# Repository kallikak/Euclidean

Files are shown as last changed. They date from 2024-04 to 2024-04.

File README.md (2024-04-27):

# Euclidean

This is the repository for the code for The EUCLIDEAN synthesiser. The main sketch is in the Euclid folder, but to build it some small changes need to be made to the Teensyduino environment.

- In order to use the Ensemble effect, the two files effect_ensemble.c and effect_ensemble.h need to be added to the audio library, and effect_ensemble.h added to the Audio.h header.

- The ST7735_t3 library is used for the LCD. The fonts I use are in the Fonts folder, and need to be added to the library if not already present.

- The other libraries needed are:
  - IntervalTimer
  - Bounce2mcp
  - Adafruit_MCP23017
  - MIDI
  - USBHost_t36
  - SD_t3.h
  - ADC (only needed if for some reason the pots are particularly noisy/jittery)

- You cannot use the default Audio Library GUI with the code from Euclid.ino because it doesn't recognise AudioEffectEnsemble.  The easiest change is to make it AudioEffectChorus  instead (and change AudioConnection patchCord60(chorus, 1, effectmixR, 1) to AudioConnection patchCord60(chorus, 0, effectmixR, 1)), but remember to change it back if you make changes and want to update.

- Compile with USB type set to Serial + MIDI + Audio, and no harm overclocking to 816MHz.

- Prebuilt hex files are provided for both Teensy 4.0 and Teensy 4.1.

A User Guide for the synthesizer is here: http://thewessens.net/Euclid/Docs/User/euclideaninfo.html

A Build Guide for the kit is here: http://thewessens.net/Euclid/Docs/Build/euclideanbuild.html

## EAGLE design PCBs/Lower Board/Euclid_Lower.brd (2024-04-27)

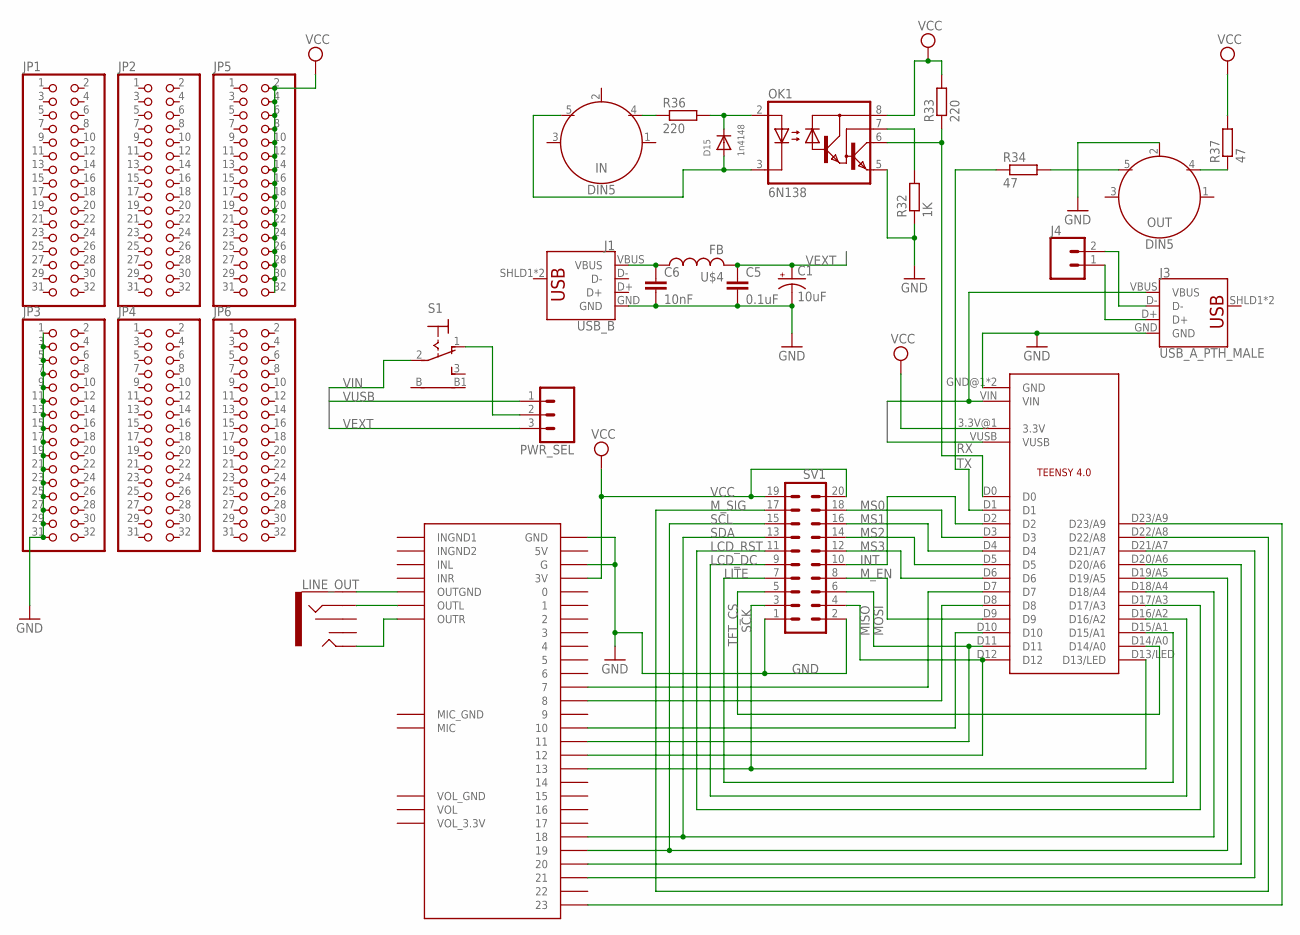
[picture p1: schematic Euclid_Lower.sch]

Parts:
C1: 10uF; TT5D6
C5: 0.1uF; C025-025X050
C6: 10nF; C025-025X050
D15: 1n4148; DO-1N4148
IN: DIN5; DIN5-RA-PTH
J1: USB_B; USB-B-NO-OVERHANG
J3: USB_A_PTH_MALE; USB-A-H
J4: CONN_02; 1X02
JP1, JP2, JP3, JP4, JP5, JP6: PINHD-2X16; 2X16
LINE_OUT: AUDIO_JACK_3.5MM_KIT; AUDIO-JACK-KIT
OK1: 6N138; DIL08
OUT: DIN5; DIN5-RA-PTH
PWR_SEL: 455-1750-1-ND; 1X03
R32: 1K; 0207/10
R33, R36: 220; 0207/10
R34, R37: 47; 0207/10
S1: 9070-1W
SV1: MA10-2
U$1: TEENSY4.0_SIMPLE
U$3: AUDIOSHIELD
U$4: FB

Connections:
D+: J3.D+, J4.1
D-: J3.D-, J4.2
GND: C1.-, C5.2, C6.2, J1.GND, J3.GND, JP3.1, JP3.3, JP3.5, JP3.7, JP3.9, JP3.11, JP3.13, JP3.15, JP3.17, JP3.19, JP3.21, JP3.23, JP3.25, JP3.27, JP3.29, JP3.31, OK1.5 (GND), OUT.2, R32.1, SV1.1, SV1.2, U$1.GND@1 (GND), U$1.GND@2 (GND), U$3.G, U$3.GND
INT: SV1.10, U$1.D2
LCD_DC: SV1.9, U$1.D16/A2
LCD_RST: SV1.11, U$1.D17/A3
LITE: SV1.7, U$1.D15/A1
MISO: SV1.4, U$1.D12, U$3.12
MOSI: SV1.6, U$1.D11, U$3.11
MS0: SV1.18, U$1.D3
MS1: SV1.16, U$1.D4
MS2: SV1.14, U$1.D5
MS3: SV1.12, U$1.D6
M_EN: SV1.8, U$1.D9
M_SIG: SV1.17, U$1.D22/A8
unnamed: U$1.D20/A6, U$3.20
unnamed: U$1.D21/A7, U$3.21
unnamed: U$1.D23/A9, U$3.23
unnamed: U$1.D10, U$3.10
unnamed: U$1.D7, U$3.7
unnamed: U$1.D8, U$3.8
unnamed: PWR_SEL.2, S1.1 (O)
unnamed: OUT.5, R34.2
unnamed: OK1.7 (VB), R32.2
unnamed: D15.A, IN.5, OK1.3 (C)
unnamed: D15.C, OK1.2 (A), R36.2
unnamed: IN.4, R36.1
unnamed: LINE_OUT.SLEEVE, U$3.OUTGND
unnamed: C6.1, J1.VBUS, U$4.P$1 (1)
unnamed: OUT.4, R37.1
unnamed: LINE_OUT.RING, U$3.OUTL
unnamed: LINE_OUT.TIP, U$3.OUTR
RX: OK1.6 (VO), R33.1, U$1.D0
SCK: SV1.3, U$1.D13/LED, U$3.13
SCL: SV1.15, U$1.D19/A5, U$3.19
SDA: SV1.13, U$1.D18/A4, U$3.18
TFT_CS: SV1.5, U$1.D14/A0
TX: R34.1, U$1.D1
VCC: JP5.2, JP5.4, JP5.6, JP5.8, JP5.10, JP5.12, JP5.14, JP5.16, JP5.18, JP5.20, JP5.22, JP5.24, JP5.26, JP5.28, JP5.30, JP5.32, OK1.8 (VCC), R33.2, R37.2, SV1.19, SV1.20, U$1.3.3V@1 (3.3V), U$3.3V
VEXT: C1.+, C5.1, PWR_SEL.3, U$4.P$2 (2)
VIN: J3.VBUS, S1.2, U$1.VIN
VUSB: PWR_SEL.1, U$1.VUSB

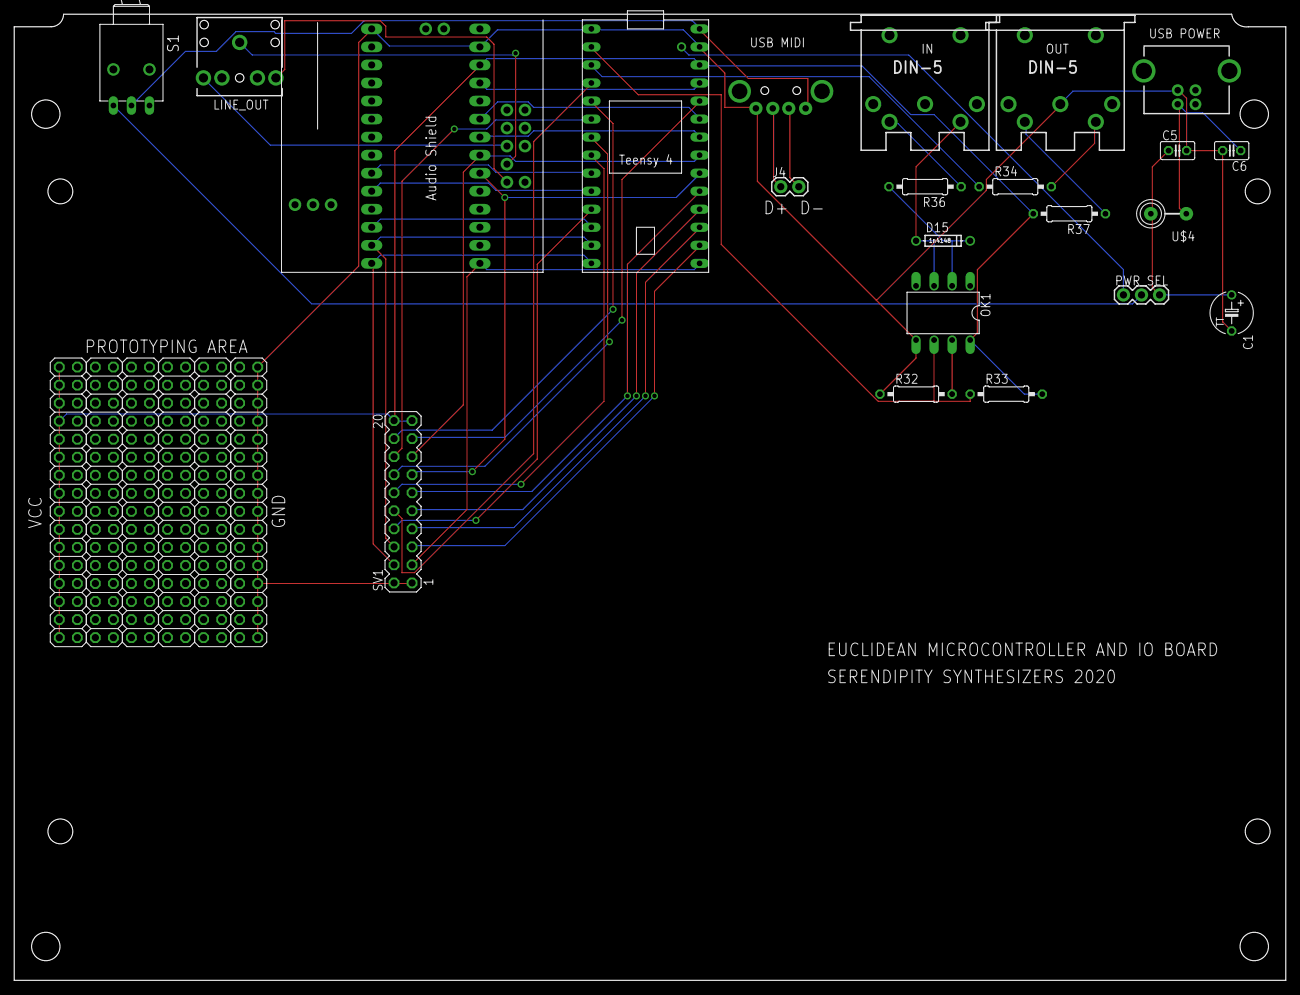
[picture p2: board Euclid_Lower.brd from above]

Board: 2 copper layers, 179.1 x 136.1 mm, 28 parts (1 on the bottom side), 42 nets.

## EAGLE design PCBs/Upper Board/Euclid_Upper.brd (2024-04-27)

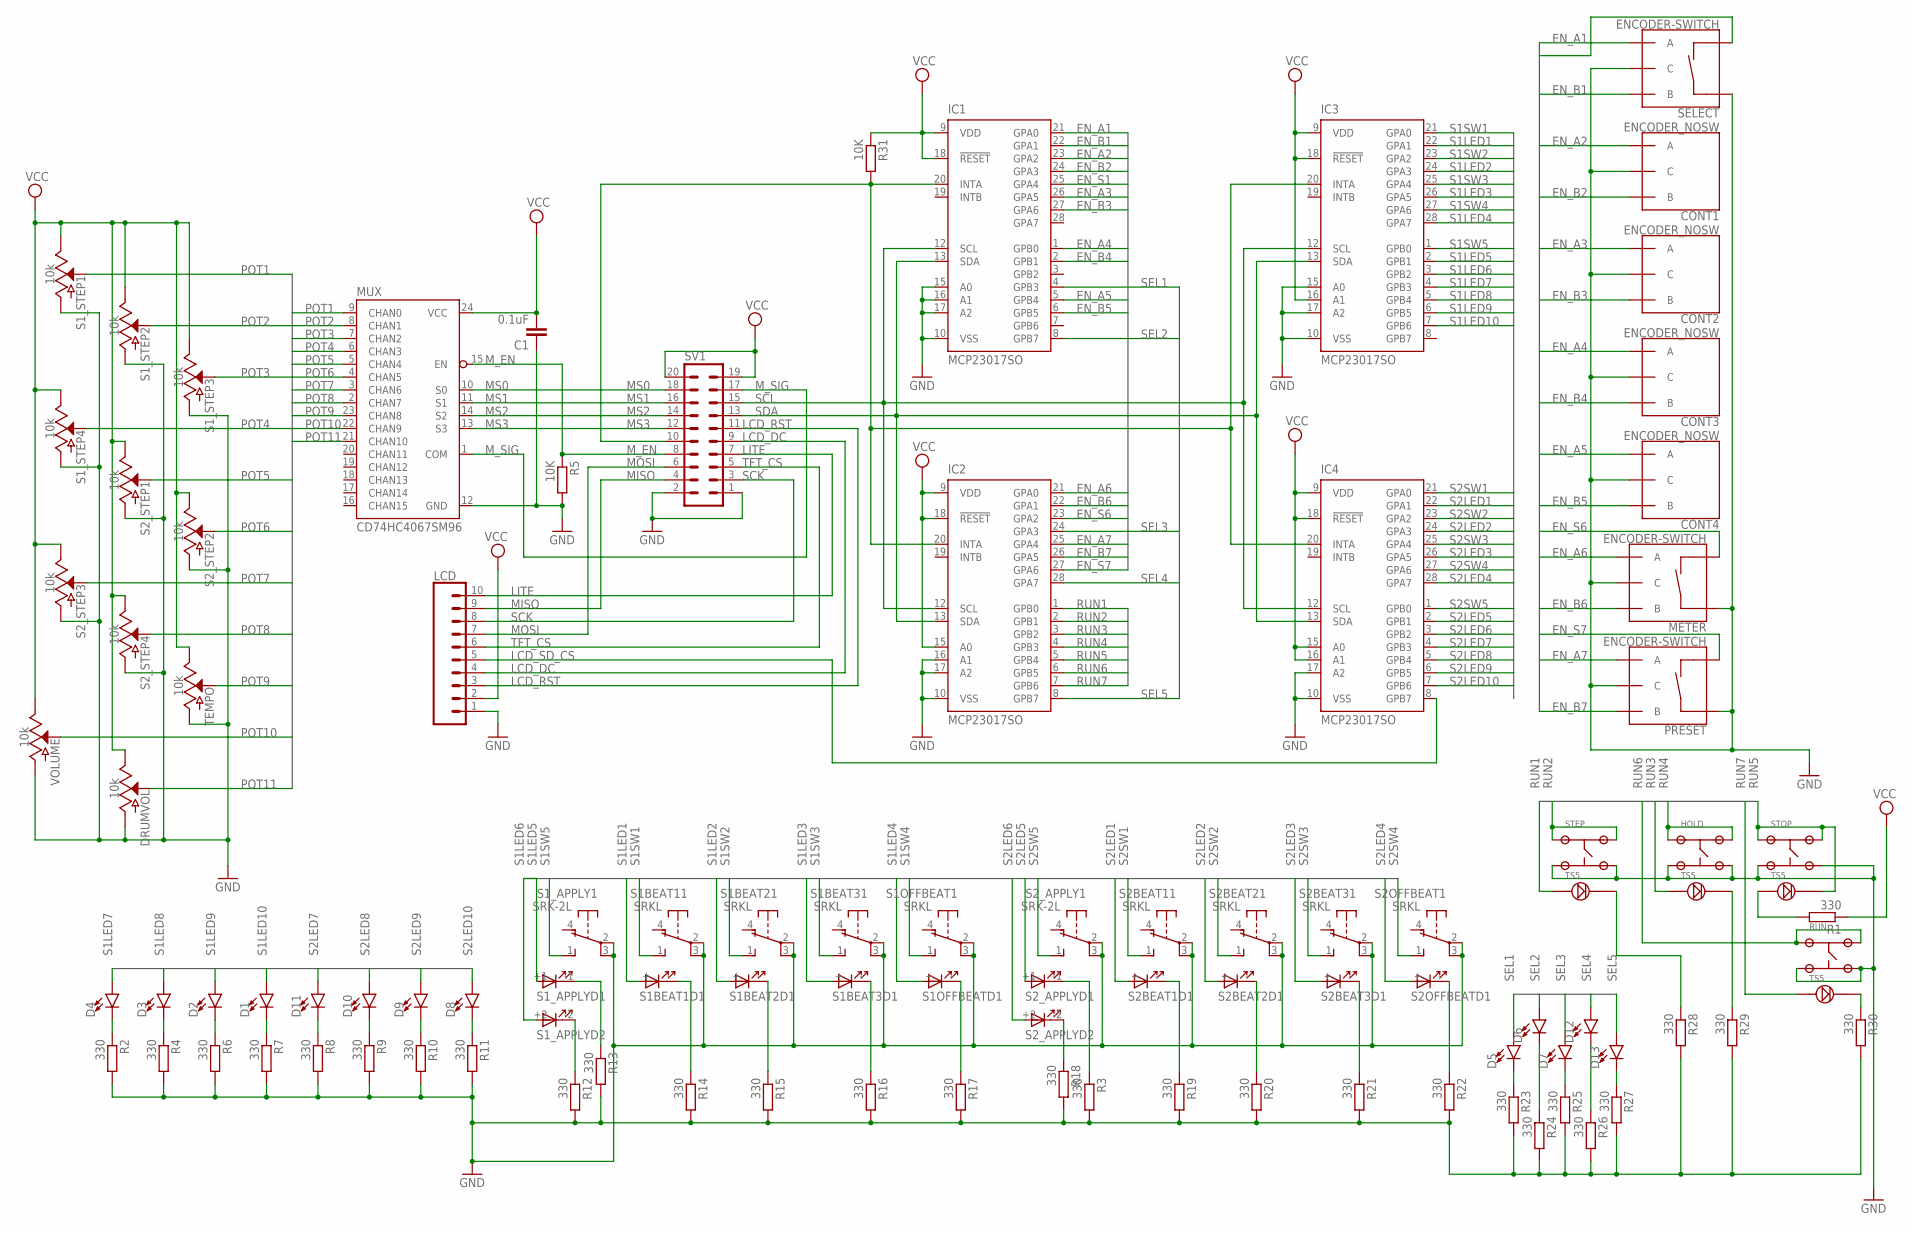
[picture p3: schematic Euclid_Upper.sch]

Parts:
C1: 0.1uF; C0603
CONT1, CONT2, CONT3, CONT4: ENCODER_NOSW
D1, D2, D3, D4, D5, D6, D7, D8, D9, D10, D11, D12, D13: LED3MM; LED_3MM
DRUMVOL: 10k; POT-PTH-ALPS
HOLD: TS5
IC1, IC2, IC3, IC4: MCP23017SO; SO28W
LCD: CONN_10"; 1X10
METER: ENCODER-SWITCH; ROTARY_ENC_PLAIN
MUX: CD74HC4067SM96; SSOP24
PRESET: ENCODER-SWITCH; ROTARY_ENC_PLAIN
R1, R2, R3, R4, R6, R7, R8, R9, R10, R11, R12, R13, R14, R15, R16, R17, R18, R19, R20, R21, R22, R23, R24, R25, R26, R27, R28, R29, R30: 330; R0603
R5, R31: 10K; R0603
RUN: TS5
S1BEAT1, S1BEAT2, S1BEAT3, S1OFFBEAT, S2BEAT1, S2BEAT2, S2BEAT3, S2OFFBEAT: SRKL
S1_APPLY, S2_APPLY: SRK-2L; SRK2L
S1_STEP1, S1_STEP2, S1_STEP3, S1_STEP4, S2_STEP1, S2_STEP2, S2_STEP3, S2_STEP4: 10k; POT-PTH-ALPS
SELECT: ENCODER-SWITCH; ROTARY_ENC_PLAIN
STEP: TS5
STOP: TS5
SV1: MA10-2
TEMPO: 10k; POT-PTH-ALPS
VOLUME: 10k; POT-PTH-ALPS

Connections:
EN_A1: IC1.21 (GPA0), SELECT.A
EN_A2: CONT1.A, IC1.23 (GPA2)
EN_A3: CONT2.A, IC1.26 (GPA5)
EN_A4: CONT3.A, IC1.1 (GPB0)
EN_A5: CONT4.A, IC1.5 (GPB4)
EN_A6: IC2.21 (GPA0), METER.A
EN_A7: IC2.25 (GPA4), PRESET.A
EN_B1: IC1.22 (GPA1), SELECT.B
EN_B2: CONT1.B, IC1.24 (GPA3)
EN_B3: CONT2.B, IC1.27 (GPA6)
EN_B4: CONT3.B, IC1.2 (GPB1)
EN_B5: CONT4.B, IC1.6 (GPB5)
EN_B6: IC2.22 (GPA1), METER.B
EN_B7: IC2.26 (GPA5), PRESET.B
EN_S1: IC1.25 (GPA4), SELECT.SW-
EN_S6: IC2.23 (GPA2), METER.SW-
EN_S7: IC2.27 (GPA6), PRESET.SW-
GND: C1.1, CONT1.C, CONT2.C, CONT3.C, CONT4.C, DRUMVOL.P$3 (A), HOLD.3, HOLD.4, IC1.10 (VSS), IC1.15 (A0), IC1.16 (A1), IC1.17 (A2), IC2.10 (VSS), IC2.16 (A1), IC2.17 (A2), IC3.10 (VSS), IC3.15 (A0), IC3.17 (A2), IC4.10 (VSS), IC4.17 (A2), LCD.1, METER.C, METER.SW+, MUX.12 (GND), PRESET.C, PRESET.SW+, R2.2, R3.2, R4.2, R5.2, R6.2, R7.2, R8.2, R9.2, R10.2, R11.2, R12.2, R13.2, R14.2, R15.2, R16.2, R17.2, R18.2, R19.2, R20.2, R21.2, R22.2, R23.2, R24.2, R25.2, R26.2, R27.2, R28.2, R29.2, R30.2, RUN.3, RUN.4, S1BEAT1.2, S1BEAT1.3, S1BEAT2.2, S1BEAT2.3, S1BEAT3.2, S1BEAT3.3, S1OFFBEAT.2, S1OFFBEAT.3, S1_APPLY.2, S1_APPLY.3, S1_STEP1.P$3 (A), S1_STEP2.P$3 (A), S1_STEP3.P$3 (A), S1_STEP4.P$3 (A), S2BEAT1.2, S2BEAT1.3, S2BEAT2.2, S2BEAT2.3, S2BEAT3.2, S2BEAT3.3, S2OFFBEAT.2, S2OFFBEAT.3, S2_APPLY.2, S2_APPLY.3, S2_STEP1.P$3 (A), S2_STEP2.P$3 (A), S2_STEP3.P$3 (A), S2_STEP4.P$3 (A), SELECT.C, SELECT.SW+, STEP.3, STEP.4, STOP.3, STOP.4, SV1.1, SV1.2, TEMPO.P$3 (A), VOLUME.P$3 (A)
LCD_DC: LCD.4, SV1.9
LCD_RST: LCD.3, SV1.11
LCD_SD_CS: IC4.8 (GPB7), LCD.5
LITE: LCD.10, SV1.7
MISO: LCD.9, SV1.4
MOSI: LCD.7, SV1.6
MS0: MUX.10 (S0), SV1.18
MS1: MUX.11 (S1), SV1.16
MS2: MUX.14 (S2), SV1.14
MS3: MUX.13 (S3), SV1.12
M_EN: MUX.15 (EN), R5.1, SV1.8
M_SIG: MUX.1 (COM), SV1.17
unnamed: IC1.20 (INTA), IC2.20 (INTA), IC3.20 (INTA), IC4.20 (INTA), R31.2, SV1.10
unnamed: R12.1, S1_APPLY.-2 (C)
unnamed: D8.K (C), R11.1
unnamed: R13.1, S1_APPLY.-1 (C)
unnamed: R14.1, S1BEAT1.- (C)
unnamed: R15.1, S1BEAT2.- (C)
unnamed: R16.1, S1BEAT3.- (C)
unnamed: R17.1, S1OFFBEAT.- (C)
unnamed: D9.K (C), R10.1
unnamed: D10.K (C), R9.1
unnamed: D11.K (C), R8.1
unnamed: R18.1, S2_APPLY.-2 (C)
unnamed: D1.K (C), R7.1
unnamed: D3.K (C), R4.1
unnamed: D4.K (C), R2.1
unnamed: D2.K (C), R6.1
unnamed: R21.1, S2BEAT3.- (C)
unnamed: R20.1, S2BEAT2.- (C)
unnamed: D5.K (C), R23.1
unnamed: R3.1, S2_APPLY.-1 (C)
unnamed: R19.1, S2BEAT1.- (C)
unnamed: D6.K (C), R24.1
unnamed: D7.K (C), R25.1
unnamed: R22.1, S2OFFBEAT.- (C)
unnamed: R30.1, RUN.5
unnamed: R28.1, STEP.5
unnamed: D12.K (C), R26.1
unnamed: R1.2, STOP.6
unnamed: HOLD.5, R29.1
unnamed: D13.K (C), R27.1
POT1: MUX.9 (CHAN0), S1_STEP1.P$2 (S)
POT2: MUX.8 (CHAN1), S1_STEP2.P$2 (S)
POT3: MUX.7 (CHAN2), S1_STEP3.P$2 (S)
POT4: MUX.6 (CHAN3), S1_STEP4.P$2 (S)
POT5: MUX.5 (CHAN4), S2_STEP1.P$2 (S)
POT6: MUX.4 (CHAN5), S2_STEP2.P$2 (S)
POT7: MUX.3 (CHAN6), S2_STEP3.P$2 (S)
POT8: MUX.2 (CHAN7), S2_STEP4.P$2 (S)
POT9: MUX.23 (CHAN8), TEMPO.P$2 (S)
POT10: MUX.22 (CHAN9), VOLUME.P$2 (S)
POT11: DRUMVOL.P$2 (S), MUX.21 (CHAN10)
RUN1: IC2.1 (GPB0), STEP.6
RUN2: IC2.2 (GPB1), STEP.1, STEP.2
RUN3: HOLD.6, IC2.3 (GPB2)
RUN4: HOLD.1, HOLD.2, IC2.4 (GPB3)
RUN5: IC2.5 (GPB4), STOP.1, STOP.2, STOP.5
RUN6: IC2.6 (GPB5), RUN.1, RUN.2
RUN7: IC2.7 (GPB6), RUN.6
S1LED1: IC3.22 (GPA1), S1BEAT1.+ (A)
S1LED2: IC3.24 (GPA3), S1BEAT2.+ (A)
S1LED3: IC3.26 (GPA5), S1BEAT3.+ (A)
S1LED4: IC3.28 (GPA7), S1OFFBEAT.+ (A)
S1LED5: IC3.2 (GPB1), S1_APPLY.+1 (A)
S1LED6: IC3.3 (GPB2), S1_APPLY.+2 (A)
S1LED7: D4.A, IC3.4 (GPB3)
S1LED8: D3.A, IC3.5 (GPB4)
S1LED9: D2.A, IC3.6 (GPB5)
S1LED10: D1.A, IC3.7 (GPB6)
S1SW1: IC3.21 (GPA0), S1BEAT1.1 (S)
S1SW2: IC3.23 (GPA2), S1BEAT2.1 (S)
S1SW3: IC3.25 (GPA4), S1BEAT3.1 (S)
S1SW4: IC3.27 (GPA6), S1OFFBEAT.1 (S)
S1SW5: IC3.1 (GPB0), S1_APPLY.1 (S)
S2LED1: IC4.22 (GPA1), S2BEAT1.+ (A)
S2LED2: IC4.24 (GPA3), S2BEAT2.+ (A)
S2LED3: IC4.26 (GPA5), S2BEAT3.+ (A)
S2LED4: IC4.28 (GPA7), S2OFFBEAT.+ (A)
S2LED5: IC4.2 (GPB1), S2_APPLY.+1 (A)
S2LED6: IC4.3 (GPB2), S2_APPLY.+2 (A)
S2LED7: D11.A, IC4.4 (GPB3)
S2LED8: D10.A, IC4.5 (GPB4)
S2LED9: D9.A, IC4.6 (GPB5)
S2LED10: D8.A, IC4.7 (GPB6)
S2SW1: IC4.21 (GPA0), S2BEAT1.1 (S)
S2SW2: IC4.23 (GPA2), S2BEAT2.1 (S)
S2SW3: IC4.25 (GPA4), S2BEAT3.1 (S)
S2SW4: IC4.27 (GPA6), S2OFFBEAT.1 (S)
S2SW5: IC4.1 (GPB0), S2_APPLY.1 (S)
SCK: LCD.8, SV1.3
SCL: IC1.12 (SCL), IC2.12 (SCL), IC3.12 (SCL), IC4.12 (SCL), SV1.15
SDA: IC1.13 (SDA), IC2.13 (SDA), IC3.13 (SDA), IC4.13 (SDA), SV1.13
SEL1: D5.A, IC1.4 (GPB3)
SEL2: D6.A, IC1.8 (GPB7)
SEL3: D7.A, IC2.24 (GPA3)
SEL4: D12.A, IC2.28 (GPA7)
SEL5: D13.A, IC2.8 (GPB7)
TFT_CS: LCD.6, SV1.5
VCC: C1.2, DRUMVOL.P$1 (E), IC1.9 (VDD), IC1.18 (!RESET), IC2.9 (VDD), IC2.15 (A0), IC2.18 (!RESET), IC3.9 (VDD), IC3.16 (A1), IC3.18 (!RESET), IC4.9 (VDD), IC4.15 (A0), IC4.16 (A1), IC4.18 (!RESET), LCD.2, MUX.24 (VCC), R1.1, R31.1, S1_STEP1.P$1 (E), S1_STEP2.P$1 (E), S1_STEP3.P$1 (E), S1_STEP4.P$1 (E), S2_STEP1.P$1 (E), S2_STEP2.P$1 (E), S2_STEP3.P$1 (E), S2_STEP4.P$1 (E), SV1.19, SV1.20, TEMPO.P$1 (E), VOLUME.P$1 (E)

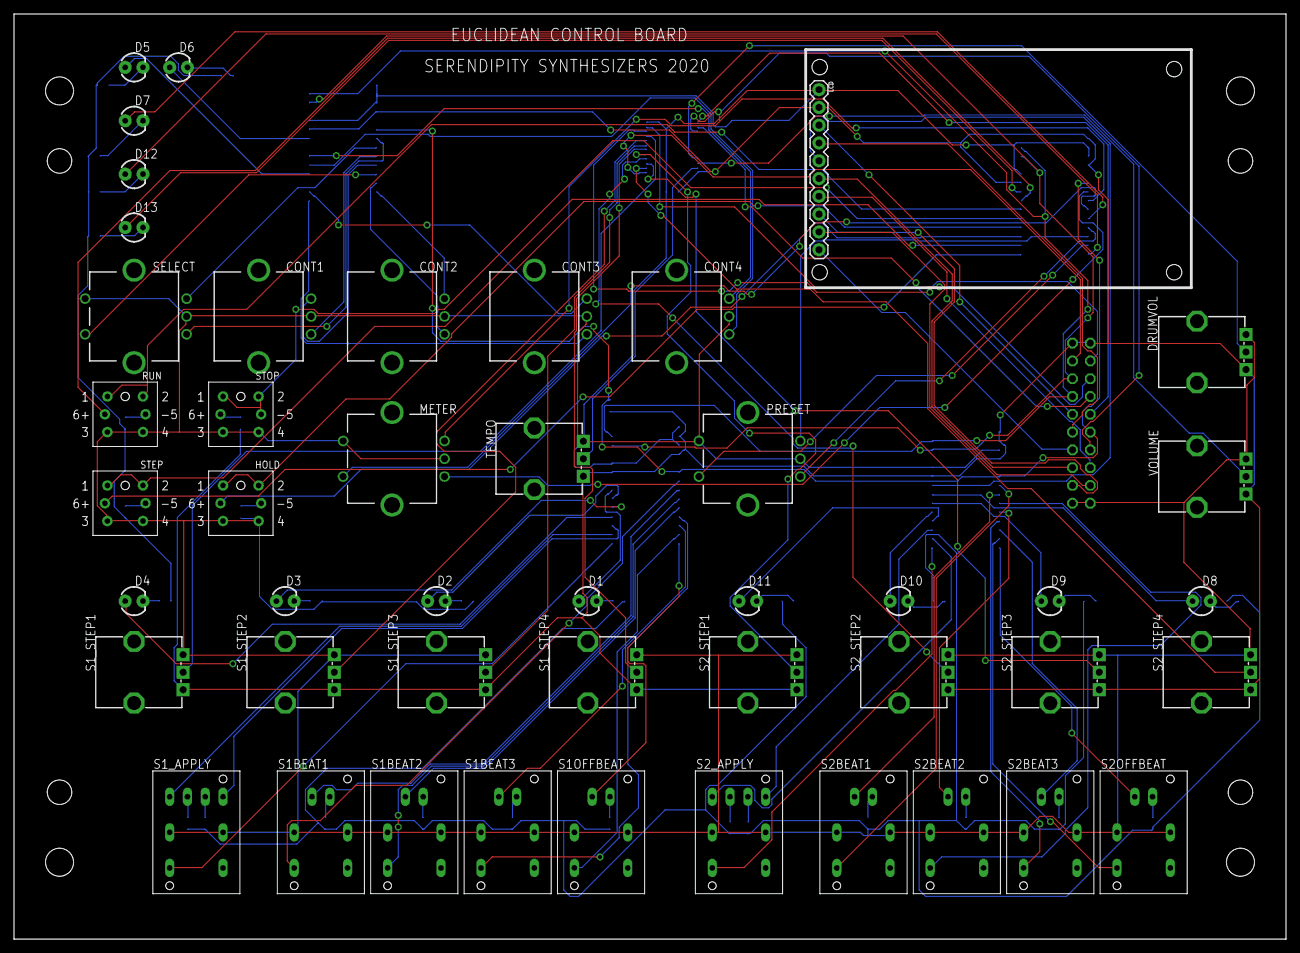
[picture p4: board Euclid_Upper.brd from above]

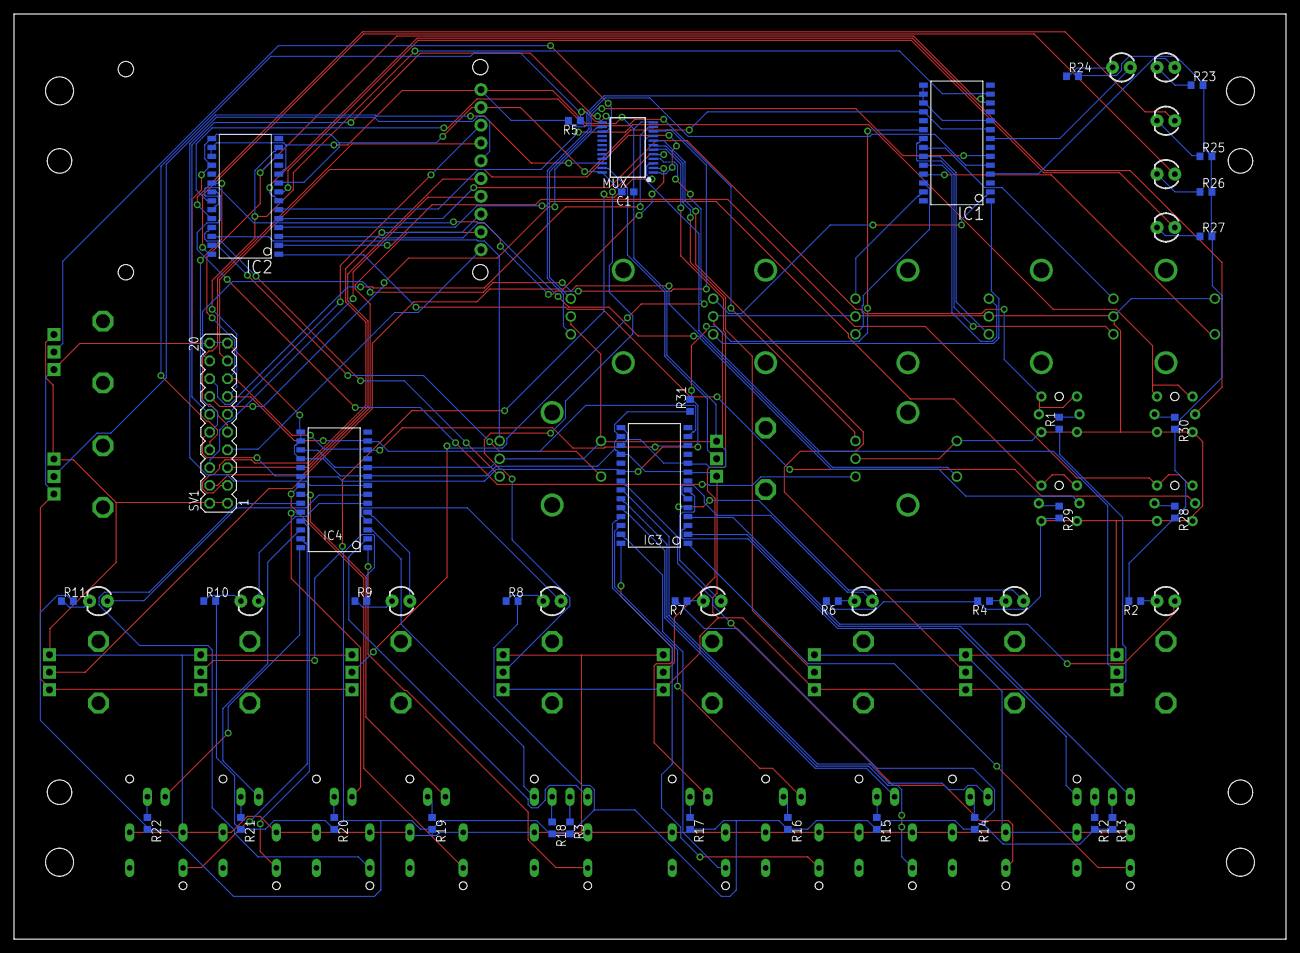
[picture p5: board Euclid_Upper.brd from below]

Board: 2 copper layers, 181.6 x 132.1 mm, 84 parts (38 on the bottom side), 118 nets.

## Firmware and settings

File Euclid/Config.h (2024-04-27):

#pragma once

#define PROTOTYPE 0

#define MAX_STEP 16
#define MAX_SAMPLESET_NAME_LENGTH 20

#define DEBUG_SERIAL 0

#include <Audio.h>

/*
#define WAVEFORM_SINE              0
#define WAVEFORM_SAWTOOTH          1
#define WAVEFORM_SQUARE            2
#define WAVEFORM_TRIANGLE          3
#define WAVEFORM_ARBITRARY         4
#define WAVEFORM_PULSE             5
#define WAVEFORM_SAWTOOTH_REVERSE  6
#define WAVEFORM_SAMPLE_HOLD       7
#define WAVEFORM_TRIANGLE_VARIABLE 8
*/

typedef enum 
{
  SINE = WAVEFORM_SINE,
  TRIANGLE = WAVEFORM_TRIANGLE,
  VAR_TRIANGLE = WAVEFORM_TRIANGLE_VARIABLE,
  SQUARE = WAVEFORM_SQUARE,
  SAWTOOTH = WAVEFORM_SAWTOOTH,
  REV_SAWTOOTH = WAVEFORM_SAWTOOTH_REVERSE,
  PULSE = WAVEFORM_PULSE,
  S_AND_H = WAVEFORM_SAMPLE_HOLD
} waveshape;
  
typedef int ccInt;  // for 0 to 127 control values

typedef struct
{
  float freq; // this is a fractional MIDI note value
  waveshape shape;
  ccInt pwamt;
  bool pwm;
  ccInt modamt;
  int subfreq;  // divisor from 2 to 16
  waveshape subshape;
  ccInt detune; // support +/- semitone
} oscillatorCfg;

typedef struct
{
  ccInt attack;
  ccInt decay;
} envelopeCfg;

typedef struct
{
  waveshape shape;
  ccInt rate;
} modulatorCfg;

typedef enum
{
  FREE,
  CHROMATIC,
  DIATONIC,
  DIATONIC_M,
  PENTATONIC,
  PENTATONIC_M,
  PYTHAGOREAN,
  PYTHAGOREAN_M,
  JUST,
  JUST_M
} quantisation;

typedef struct
{
  quantisation scale;
  int transpose;  // -12 to +12
} tuningCfg;

typedef struct
{
  ccInt osclevel[2];
  bool oscmute[2];
  ccInt sublevel[2];
  bool submute[2];
} mixerCfg;

typedef struct
{
  ccInt cutoff;
  ccInt resonance;
  ccInt envamt;   // from -64 to 63
  ccInt modamt;
} filterCfg;

typedef struct
{
   int steps[4]; // -MAX_STEP to MAX_STEP
   bool applyOsc;
   bool applySub;
   bool advBeat[3];
   bool advOffbeat;
} sequencerCfg;

typedef struct
{
  ccInt tempo;
  int r1[3];
  int r2[3];
  int r3[3];
} rhythmCfg;

typedef enum
{
  NONE,
  CHORUS,
  FLANGE,
  DELAY,
  CHORUS_DELAY
} effect;

typedef enum
{
  BYPASS,
  SLOW,
  MEDIUM,
  FAST
} effect_preset;

typedef struct
{
  effect active;
  effect_preset chorus; // use preset index - 0 means off
  effect_preset flange;
  effect_preset delay;
} effectsCfg;

typedef enum
{
  BT_OFF,
  BT_SEL,
  BT_ONE,
  BT_ALL,
  BT_NONE
} beatState;

typedef struct
{
  beatState beatstate;
  beatState offbeatstate;
  int beats[4];
  char sampleset[MAX_SAMPLESET_NAME_LENGTH + 1];
} drumCfg;

typedef struct
{
  oscillatorCfg osc[2]; 
  mixerCfg      mix;
  envelopeCfg   env;
  modulatorCfg  lfo;
  filterCfg     filter;
  tuningCfg     tuning;
  effectsCfg    eff;
  sequencerCfg  seq[2];
  rhythmCfg     rhythm;
  drumCfg       drum;
} euclid_config, *config_ptr;

extern config_ptr config;

extern bool useMIDIClock;

extern bool needsKitUpdate;
extern bool needsOffbeatUpdate;

void setDefaultConfig();

waveshape getNextWaveshape(bool osc, bool sub, bool lfo, int i, bool back);
const char *waveshapeStr(waveshape w, bool full);
const char *quantisationStr(quantisation q, bool full);
const char *effectStr(effect e);
const char *effectPresetStr(effect_preset p);
const char *beatstateStr(beatState state);

void printOscConfig(int i, oscillatorCfg *cfg);
void printMixConfig(mixerCfg *cfg);
void printEnvelopeConfig(envelopeCfg *cfg);
void printModulatorConfig(modulatorCfg *cfg);
void printFilterConfig(filterCfg *cfg);
void printTuningConfig(tuningCfg *cfg);
void printSequencerConfig(int i, sequencerCfg *cfg);
void printRhythmConfig(rhythmCfg *cfg);
void printEffectsConfig(effectsCfg *cfg);
void printDrumConfig(drumCfg *cfg);
void printConfig(config_ptr cfg);

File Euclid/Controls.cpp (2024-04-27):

#define USE_ADC_LIB 1

#include <IntervalTimer.h>

#if USE_ADC_LIB
#include <ADC.h>
#endif

#include "Adafruit_MCP23X17.h"
#include "Rotary.h"
#include <Bounce2mcp.h>
#include "LCD.h"

#include "Config.h"
#include "Utility.h"
#include "Sequencer.h"
#include "Synth.h"
#include "Presets.h"
#include "Controls.h"
#include "MIDIManager.h"
#include "drum_samples.h"
#include "Drums.h"

#if USE_ADC_LIB
ADC *adc = new ADC(); // adc object;
#endif

static IntervalTimer shifttimer;

#if PROTOTYPE     
#else
static bool shift = false;
#endif

static bool metershift = true;
static volatile bool toggleshiftled = false;
static bool selectledstate = true;

int selected = 0;

void shiftflashcallback()
{
  toggleshiftled = !toggleshiftled;
}

#define SELECT_O1   0
#define SELECT_O2   1
#define SELECT_OS   2
#define SELECT_ENV  3
#define SELECT_MIX  4
#define SELECT_F    5

int preset = SET_DEFAULT;
bool enablePresetButton = false;  // must have been turned first
bool saveNewPresetSelected = false;
bool choosingKit = false;
int lastupdatemillis = 0;
int activemeter = 0;

bool presetMenuMode = false;
int presetMenuSelect = -1;
void showPresetLabel(int p);

long transposeTime = -1;
#if PROTOTYPE
bool transposeMode = false;
#endif
int transpose;
void applyTranspose(unsigned long curmillis);

void setToCurTempo();

#define UPDATE_WAIT_TIME 3000
#define METER_UPDATE_WAIT_TIME 100

bool demoMode = false;
#define DEMO_TIME_PER_PRESET 8
  
static char tempstr[50] = {0};

Adafruit_MCP23X17 *expanders[] = {NULL, NULL, NULL, NULL};

typedef struct
{
  int expander;
  int pin;
  int led1pin;
  int led2pin;
  BounceMcp *debouncer;
} pushswitch;

#define NUM_SEQ_SWITCHES 10
#define NUM_SWITCHES 14

pushswitch switches[] = 
{
  {2, 0, 1, -1, NULL},   // seq 1 beat 1
  {2, 2, 3, -1, NULL},   // seq 1 beat 2
  {2, 4, 5, -1, NULL},   // seq 1 beat 3
  {2, 6, 7, -1, NULL},   // seq 1 offbeat
  {2, 8, 9, 10, NULL},   // seq 1 apply
  
  {3, 0, 1, -1, NULL},   // seq 2 beat 1
  {3, 2, 3, -1, NULL},   // seq 2 beat 2
  {3, 4, 5, -1, NULL},   // seq 2 beat 3
  {3, 6, 7, -1, NULL},   // seq 2 offbeat
  {3, 8, 9, 10, NULL},   // seq 2 apply
  
  {1,  9,  8, -1, NULL},   // pause
  {1, 11, 10, -1, NULL},   // hold
  {1, 12, -1, -1, NULL},   // stop // FIXME - button doesn't register if ledpin set to -1
  {1, 13, 14, -1, NULL},   // run
};

#define STEP_LED 8
#define HOLD_LED 10
#define RUN_LED 14

typedef struct
{
  int expander;
  int seq;
  int beat;
  int pin;
} sequencerled;

sequencerled seqleds[] = 
{
  {2, 1, 0, 11},
  {2, 1, 1, 12},
  {2, 1, 2, 13},
  {2, 1, 3, 14},
  {3, 2, 0, 11},
  {3, 2, 1, 12},
  {3, 2, 2, 13},
  {3, 2, 3, 14},
};

typedef struct
{
  int expander;
  int pin;
} selectled;

selectled selleds[] = 
{
  {0, 11},
  {0, 15},
  {1,  3},
  {1,  7},
  {1, 15},
};

#define NUM_ENCODERS 7

encoder encoders[] = {
#if PROTOTYPE
  {0,  0,  1, -1, 0x0003, false, R_START, {0, 0, 0, 0, 0, 0}, {4, 4, 4, 4, 4, 4}, NULL },
  // Freq, Quantise, Osc 1 level, Cutoff
  {0,  2,  3,  4, 0x000C, false, R_START, {40, 40, 40, 0, 0, 0}, {76, 76, 76, 10, 127, 127}, NULL },
  // PW, Attack, Sub 1 level, Res
  {0,  5,  6,  7, 0x0060, false, R_START, {0, 0, 0, 0, 0, 0}, {127, 127, 127, 127, 127, 127}, NULL },
  // Mod amt, Decay, Osc 2 level, Env amt
  {0,  8,  9, 10, 0x0300, false, R_START, {0, 0, 0, 0, 0, -64}, {127, 127, 127, 127, 127, 63},  NULL },
  // Sub-freq, Rate, Sub 2 level, Mod amt
  {0, 12, 13, 14, 0x6000, false, R_START, {2, 2, 2, 0, 0, 0}, {16, 16, 16, 127, 127, 127}, NULL },
#else
  {0,  0,  1,  4, 0x0003, false, R_START, {0, 0, 0, 0, 0, 0}, {4, 4, 4, 4, 4, 4}, NULL },
  // Freq, Quantise, Osc 1 level, Cutoff
  {0,  2,  3, -1, 0x000C, false, R_START, {40, 40, 40, 0, 0, 0}, {76, 76, 76, 10, 127, 127}, NULL },
  // PW, Attack, Sub 1 level, Res
  {0,  5,  6, -1, 0x0060, false, R_START, {0, 0, 0, 0, 0, 0}, {127, 127, 127, 127, 127, 127}, NULL },
  // Mod amt, Decay, Osc 2 level, Env amt
  {0,  8,  9, -1, 0x0300, false, R_START, {0, 0, 0, 0, 0, -64}, {127, 127, 127, 127, 127, 63},  NULL },
  // Sub-freq, Rate, Sub 2 level, Mod amt
  {0, 12, 13, -1, 0x6000, false, R_START, {2, 2, 2, 0, 0, 0}, {16, 16, 16, 127, 127, 127}, NULL },
#endif
  {1,  0,  1,  2, 0x0003, false, R_START, {1, 1, 1, 1, 1, 1}, {32, 32, 32, 32, 32, 32}, NULL }, // meter
  {1,  4,  5,  6, 0x0030, false, R_START, {0, 0, 0, 0, 0, 0}, {5, 5, 5, 5, 5, 5}, NULL } // preset
};

#define SELECT_ENC 0
#define METER_ENC 5
#define PRESET_ENC 6

pot pots[] = {
  {15, 0, 0, 0,  true, NO_ADJUST, 0, false},
  {14, 0, 0, 0,  true, NO_ADJUST, 0, false},
  {13, 0, 0, 0,  true, NO_ADJUST, 0, false},
  {12, 0, 0, 0,  true, NO_ADJUST, 0, false},
  {11, 0, 0, 0,  true, NO_ADJUST, 0, false},
  {10, 0, 0, 0,  true, NO_ADJUST, 0, false},
  { 9, 0, 0, 0,  true, NO_ADJUST, 0, false},
  { 8, 0, 0, 0,  true, NO_ADJUST, 0, false},
  { 7, 0, 0, 0, false, NO_ADJUST, 0, false},
  { 6, 0, 0, 0, false, NO_ADJUST, 0, false},
  { 5, 0, 0, 0, false, NO_ADJUST, 0, false},
};

#if PROTOTYPE
#define NUM_POTS 10
#else
#define NUM_POTS 11
#endif
#define INIT_POT_VAL -1000
#define POTLOOPSET  3 // 16
#define POTLOOPREAD 3 // 6
#define POTLOOPSKIP (POTLOOPSET + POTLOOPREAD)

#if USE_ADC_LIB
#define MAXRAWVAL 4095
#else
#define MAXRAWVAL 1023
#endif
#define MAXPOTVAL 1023
#define ZERO_RANGE 50
const float CENTRE = MAXPOTVAL / 2;
const float SCALE = CENTRE / (MAXPOTVAL - CENTRE - ZERO_RANGE);

#define S1STEP1_POT 0
#define S1STEP2_POT 1
#define S1STEP3_POT 2
#define S1STEP4_POT 3
#define S2STEP1_POT 4
#define S2STEP2_POT 5
#define S2STEP3_POT 6
#define S2STEP4_POT 7
#define TEMPO_POT 8
#define VOLUME_POT 9
#define DRUM_VOL_POT 10

#define BLOCK_TEMPO_UPDATE -1
 
uint16_t blockMillis = 0;
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

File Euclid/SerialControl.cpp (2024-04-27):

#include <string.h>
#include <ctype.h>

#include "Controls.h"
#include "LCD.h"
#include "Presets.h"
#include "Drums.h"

#define MAXLENGTH 100
#define ARGLENGTH 6
#define MAXARGS 4

void runSerialCommand();
bool saveSerialStream(int n);

typedef char Argument[ARGLENGTH];
typedef struct
{
  bool valid;
  Argument cmd;
  Argument args[MAXARGS];
} command;
  
command getcmd(char *s)
{
  command cmd = {false, "", {"", "", "", ""}};

  int i = 0;
  while (isspace(s[i]))
    i++;
  for (int k = -1; k < MAXARGS; ++k)
  {
    if (!s[i])
      break;
    while (isspace(s[i]))
      i++;
    for (int j = 0; j < ARGLENGTH; ++j)
    {
      char c = s[i];
      if (c && !isspace(c))
      {
        if (k < 0)
          cmd.cmd[j] = c;
        else
          cmd.args[k][j] = c;
        cmd.valid = true;
        i++;
      }
      else
      {
        break; 
      }
    }
  }
  
  return cmd;
}

bool isplus(char *arg)
{
  return strcmp(arg, "+") == 0;
}

bool isminus(char *arg)
{
  return strcmp(arg, "-") == 0;
}

int getargnum(char *arg, bool subone)
{
  if (isplus(arg))
    return 1;
  else if (isminus(arg))
    return -1;
  else
    return subone ? atol(arg) - 1 : atol(arg);
}

static char s_str[MAXLENGTH + 1] = {0};
static int s_index = 0;
bool getSerialInput();

void clearSerialInput()
{
  memset(s_str, 0, MAXLENGTH + 1);
  s_index = 0;
}

void checkSerialControl()
{
  if (getSerialInput())
  {
    runSerialCommand();
    clearSerialInput();
  }
}
      
bool getSerialInput()
{
  char c;
  while (s_index < MAXLENGTH && Serial.available())
  {
    c = Serial.read();
    if (c == 0x7F || c == '\b')
    {
      if (s_index)
      {
        s_str[--s_index] = '\0';
        Serial.print('X');
        Serial.flush();
      }
    }
    else if (c == '\n' || c == '\r')
    {
      Serial.println();
      return true;
    }
    else if (iscntrl(c))
    {
      // discard all the control data
      while (Serial.available())   
        c = Serial.read();
    }
    else //if (!iscntrl(c))
    {
      Serial.print(c);
      Serial.flush();
      s_str[s_index++] = c;
    }
  }
  return false;
}

void runSerialCommand()
{
  command thecmd = getcmd(s_str);
  if (!thecmd.valid)
    return;
  
//  Serial.print("Running '");
//  Serial.print(s_str);
//  Serial.println("'");
//  
//  Serial.println(thecmd.cmd);
//  for (int k = 0; k < MAXARGS; ++k)
//  {
//    if (strlen(thecmd.args[k]))
//    {
//      Serial.print("Arg ");
//      Serial.print(k + 1);
//      Serial.print(": ");
//      Serial.println(thecmd.args[k]);
//    }
//  }

  char *cmd = thecmd.cmd;
  char *a1 = strlen(thecmd.args[0]) ? thecmd.args[0] : NULL;
  char *a2 = strlen(thecmd.args[1]) ? thecmd.args[1] : NULL;
  char *a3 = strlen(thecmd.args[2]) ? thecmd.args[2] : NULL;
  char *a4 = strlen(thecmd.args[3]) ? thecmd.args[3] : NULL;
  lastupdatemillis = millis();

  if ((strcasecmp(cmd, "r") == 0 || strcasecmp(cmd, "run") == 0) && !a1)
  {
    Serial.println("Run");
    buttonPressed(RUN, 1);
  }
  else if (strcasecmp(cmd, "stop") == 0 || strcmp(cmd, ".") == 0)
  {
    Serial.println("Stop");
    buttonPressed(STOP, 1);
  }
  else if (strcasecmp(cmd, "hold") == 0 || strcasecmp(cmd, "h") == 0)
  {
    Serial.println("Hold");
    buttonPressed(HOLD, 1);
  }
  else if (strcasecmp(cmd, "pause") == 0)
  {
    Serial.println("Step");
    buttonPressed(STEP, 1);
  }
  else if (strcasecmp(cmd, "sel") == 0)
  {
    selected = getargnum(a1, true);
    selected = (selected + NUM_SELECT) % NUM_SELECT; 
    setSelectLed(selected);
    showSelectSummary(selected);
  }
  else if (strcasecmp(cmd, "turn") == 0 && a2)
  {
    int enc = atol(a1);
    if (enc > 0 && enc < 4)
    {
      int d = getargnum(a2, false);
      handleEncoderTurn(enc, d);
    }
  }
#if PROTOTYPE
  else if (strcasecmp(cmd, "press") == 0 && a1)
  {
    int enc = atol(a1);
    if (enc > 0 && enc < 4)
      handleEncoderPress(enc);
  }
#else  
  else if (strcasecmp(cmd, "shift") == 0)
  {
    handleEncoderPress(0);
  }
#endif  
  else if (strcasecmp(cmd, "step") == 0 && a3)
  {
    int s = atol(a1);
    int p = atol(a2);
    if ((s == 1 || s == 2) && (p > 0 && p < 5))
    {
      s--;
      p--;
      sequencerCfg *seqcfg = &config->seq[s];
      int value;
      if (isdigit(a3[0]))
        value = getargnum(a3, false);
       else
        value = seqcfg->steps[p] + getargnum(a3, false);
      setStepValue(s, p, value);
    }
  }
  else if (strcasecmp(cmd, "beat") == 0 && a3)
  {
    int s = atol(a1);
    int b = atol(a2);
    int o = atol(a3);
    if ((s == 1 || s == 2) && (b >= 0 && b <= 7) && (o == 0 || o == 1))
    {
      s--;
      sequencerCfg *seqcfg = &config->seq[s];
      seqcfg->advBeat[0] = b & 0x04;
      seqcfg->advBeat[1] = b & 0x02;
      seqcfg->advBeat[2] = b & 0x01;
      seqcfg->advOffbeat = o;
      showSequencerState();
    }
  }
  else if (strcasecmp(cmd, "app") == 0 && a2)
  {
    int s = atol(a1);
    int os = atol(a2);
    if ((s == 1 || s == 2) && (os >= 0 && os <= 3))
    {
      s--;
      sequencerCfg *seqcfg = &config->seq[s];
      seqcfg->applyOsc = os & 0x02;
      seqcfg->applySub = os & 0x01;
      showSequencerState();
    }
  }
  else if (strcasecmp(cmd, "meter") == 0 && a4)
  {
    int r = atol(a1);
    int i = getargnum(a2, false);
    int j = getargnum(a3, false);
    int k = getargnum(a4, false);
    if ((i > 0 && i <= j) && (j < 32) && (k >= 0 && k < j))
    {
      rhythmCfg *rcfg = &config->rhythm;
      switch (r)
      {
        case 1:
          rcfg->r1[0] = i;
          rcfg->r1[1] = j;
          rcfg->r1[2] = k;
          break;
        case 2:
          rcfg->r2[0] = i;
          rcfg->r2[1] = j;
          rcfg->r2[2] = k;
          break;
        case 3:
          rcfg->r3[0] = i;
          rcfg->r3[1] = j;
          rcfg->r3[2] = k;
          break;
        default:
          return;
      }
      updateActiveMeter(0);
    }
  }
  else if (strcasecmp(cmd, "tempo") == 0 && a1)
  {
    int curtempo = config->rhythm.tempo;
    int t = getargnum(a1, false);
    if (t < 0 || a1[0] == '+')
    {
      curtempo += t;
    }
    else
    {
      curtempo = t;
    }
    config->rhythm.tempo = curtempo;
    poly->setTempo(curtempo);
    showTempo((int)round(60000.0 / poly->tempoToDelay(curtempo)));
  }
  else if (strcasecmp(cmd, "vol") == 0 && a1)
  {      
    int value = getargnum(a1, false);
    synth->setLevel(min(max(value, 0), 127));
  }
  else if (strcasecmp(cmd, "dv") == 0 && a1)
  {      
    int value = getargnum(a1, false);
    adjustDrumsVolume(min(max(value, 0), 127));
  }
  else if (strcasecmp(cmd, "dump") == 0 && a1)
  {
    if (strcmp(a1, "*") == 0)
      dumpAllPresetsSD();
    else
      dumpPresetSD(atol(a1));
  }
  else if (strcasecmp(cmd, "pre") == 0 && a1)
  {
    long np = atol(a1);
    loadPreset(np);
    Serial.print("Setting to preset ");
    Serial.println(np);
  }
  else if (strcasecmp(cmd, "conf") == 0)
  {
    printConfig(NULL);
    Serial.println();
  }
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

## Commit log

2020-09-29 Adjusted detune limits and fixed oscillator update bug
    [Controls.cpp, Presets.cpp, SerialControl.cpp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]
2020-10-03 Fixed bug making pause too slow after changes to clocking
    [Sequencer.cpp]
2020-10-04 Sequencer properly resets on run now
    [Controls.cpp]
2021-01-16 Added eagle files and berbers
    [Euclid_Lower.brd, Euclid_Lower.sch, Euclid_Rear_Panel.brd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]
2021-01-16 Added eagle files and gerbers
    [Euclid_Lower.brd, Euclid_Lower.sch, Euclid_Rear_Panel.brd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]
2021-02-16 Further fixes to external MIDI clock startup
    [Controls.cpp, MIDIManager.cpp]
2024-04-27 New version with sample file support
    [Euclid_Lower.brd, Euclid_Lower.sch, Euclid_Rear_Panel.brd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]

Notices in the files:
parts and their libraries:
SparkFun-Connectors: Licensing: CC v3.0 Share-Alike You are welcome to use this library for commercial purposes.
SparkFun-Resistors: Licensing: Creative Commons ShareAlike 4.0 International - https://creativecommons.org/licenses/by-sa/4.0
